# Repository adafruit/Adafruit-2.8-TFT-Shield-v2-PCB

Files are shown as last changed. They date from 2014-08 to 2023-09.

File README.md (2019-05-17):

# Adafruit 2.8 TFT LCD Display Shield v2 PCBs
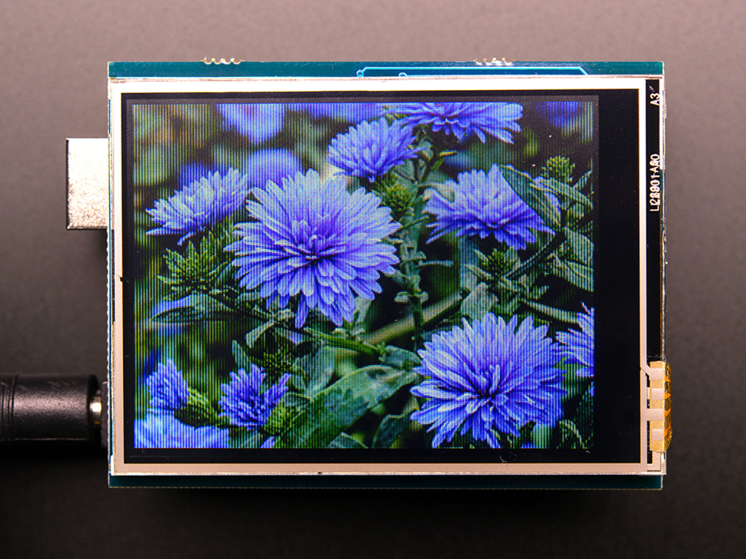
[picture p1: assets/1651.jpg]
&nbsp; 
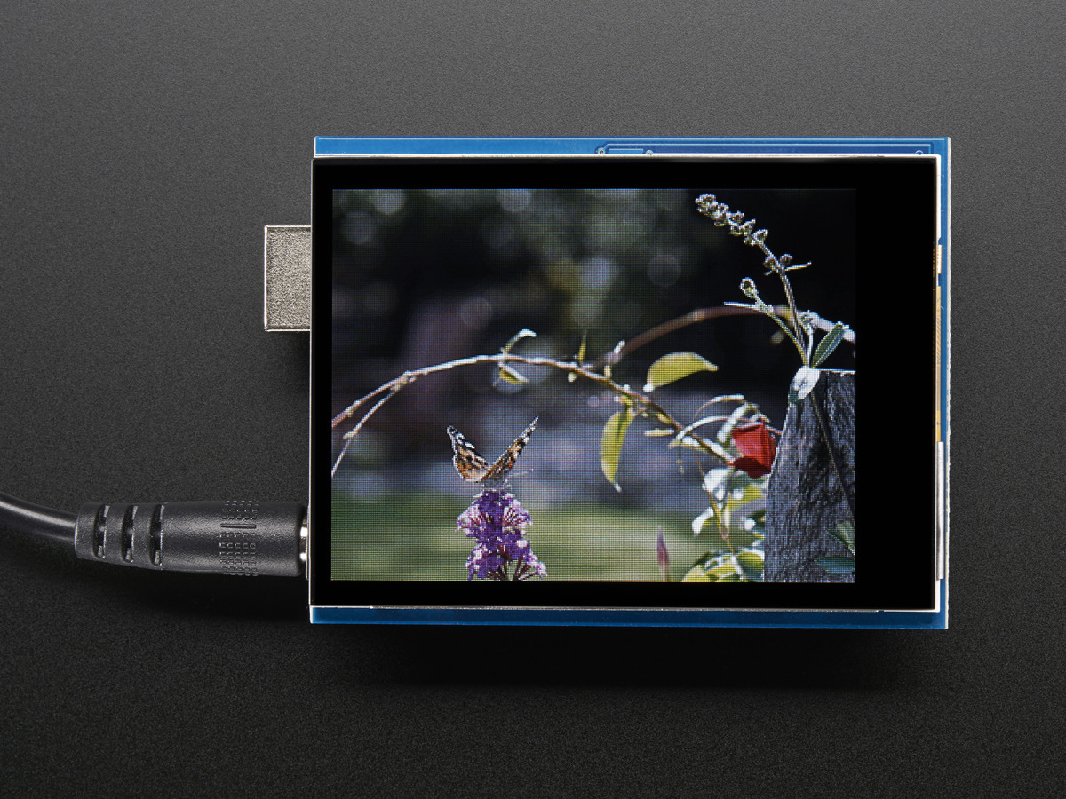
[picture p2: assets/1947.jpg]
<br />
Click to view/purchase from the Adafruit Shop:
- [2.8" TFT Touch Shield for Arduino with Resistive Touch Screen](https://www.adafruit.com/product/1651)
- [2.8" TFT Touch Shield for Arduino w/Capacitive Touch](https://www.adafruit.com/product/1947)

Spice up your Arduino project with a beautiful large touchscreen display shield with built in microSD card connection. This TFT display is big (2.8" diagonal) bright (4 white-LED backlight) and colorful (18-bit 262,000 different shades)! 240x320 pixels with individual pixel control. It has way more resolution than a black and white 128x64 display. As a bonus, these displays has a resistive or capacitive touchscreen attached to it already, so you can detect finger presses anywhere on the screen. 

We've updated our original v1 shield to an SPI display - its a tiny bit slower but uses a lot less pins and is now much easier to use with Mega & Leonardo. We also include an SPI touchscreen controller so you only need one additional pin to add a high quality touchscreen controller. Even with all the extras, the price is lower thanks to our parts sourcing & engineering skillz!

This is the PCB for the two Adafruit 2.8" TFT Shields v2 Resistive and Capacitive touch screens. 

The format is EagleCAD schematic and board layout

For more details, check out the product pages at

- https://www.adafruit.com/product/1651
- https://www.adafruit.com/product/1947

### License

Adafruit invests time and resources providing this open source design, please support Adafruit and open-source hardware by [purchasing products from Adafruit](https://www.adafruit.com)!

All text above must be included in any redistribution

Designed by Limor Fried/Ladyada for Adafruit Industries.
Creative Commons Attribution/Share-Alike, all text above must be included in any redistribution. 
See license.txt for additional information.

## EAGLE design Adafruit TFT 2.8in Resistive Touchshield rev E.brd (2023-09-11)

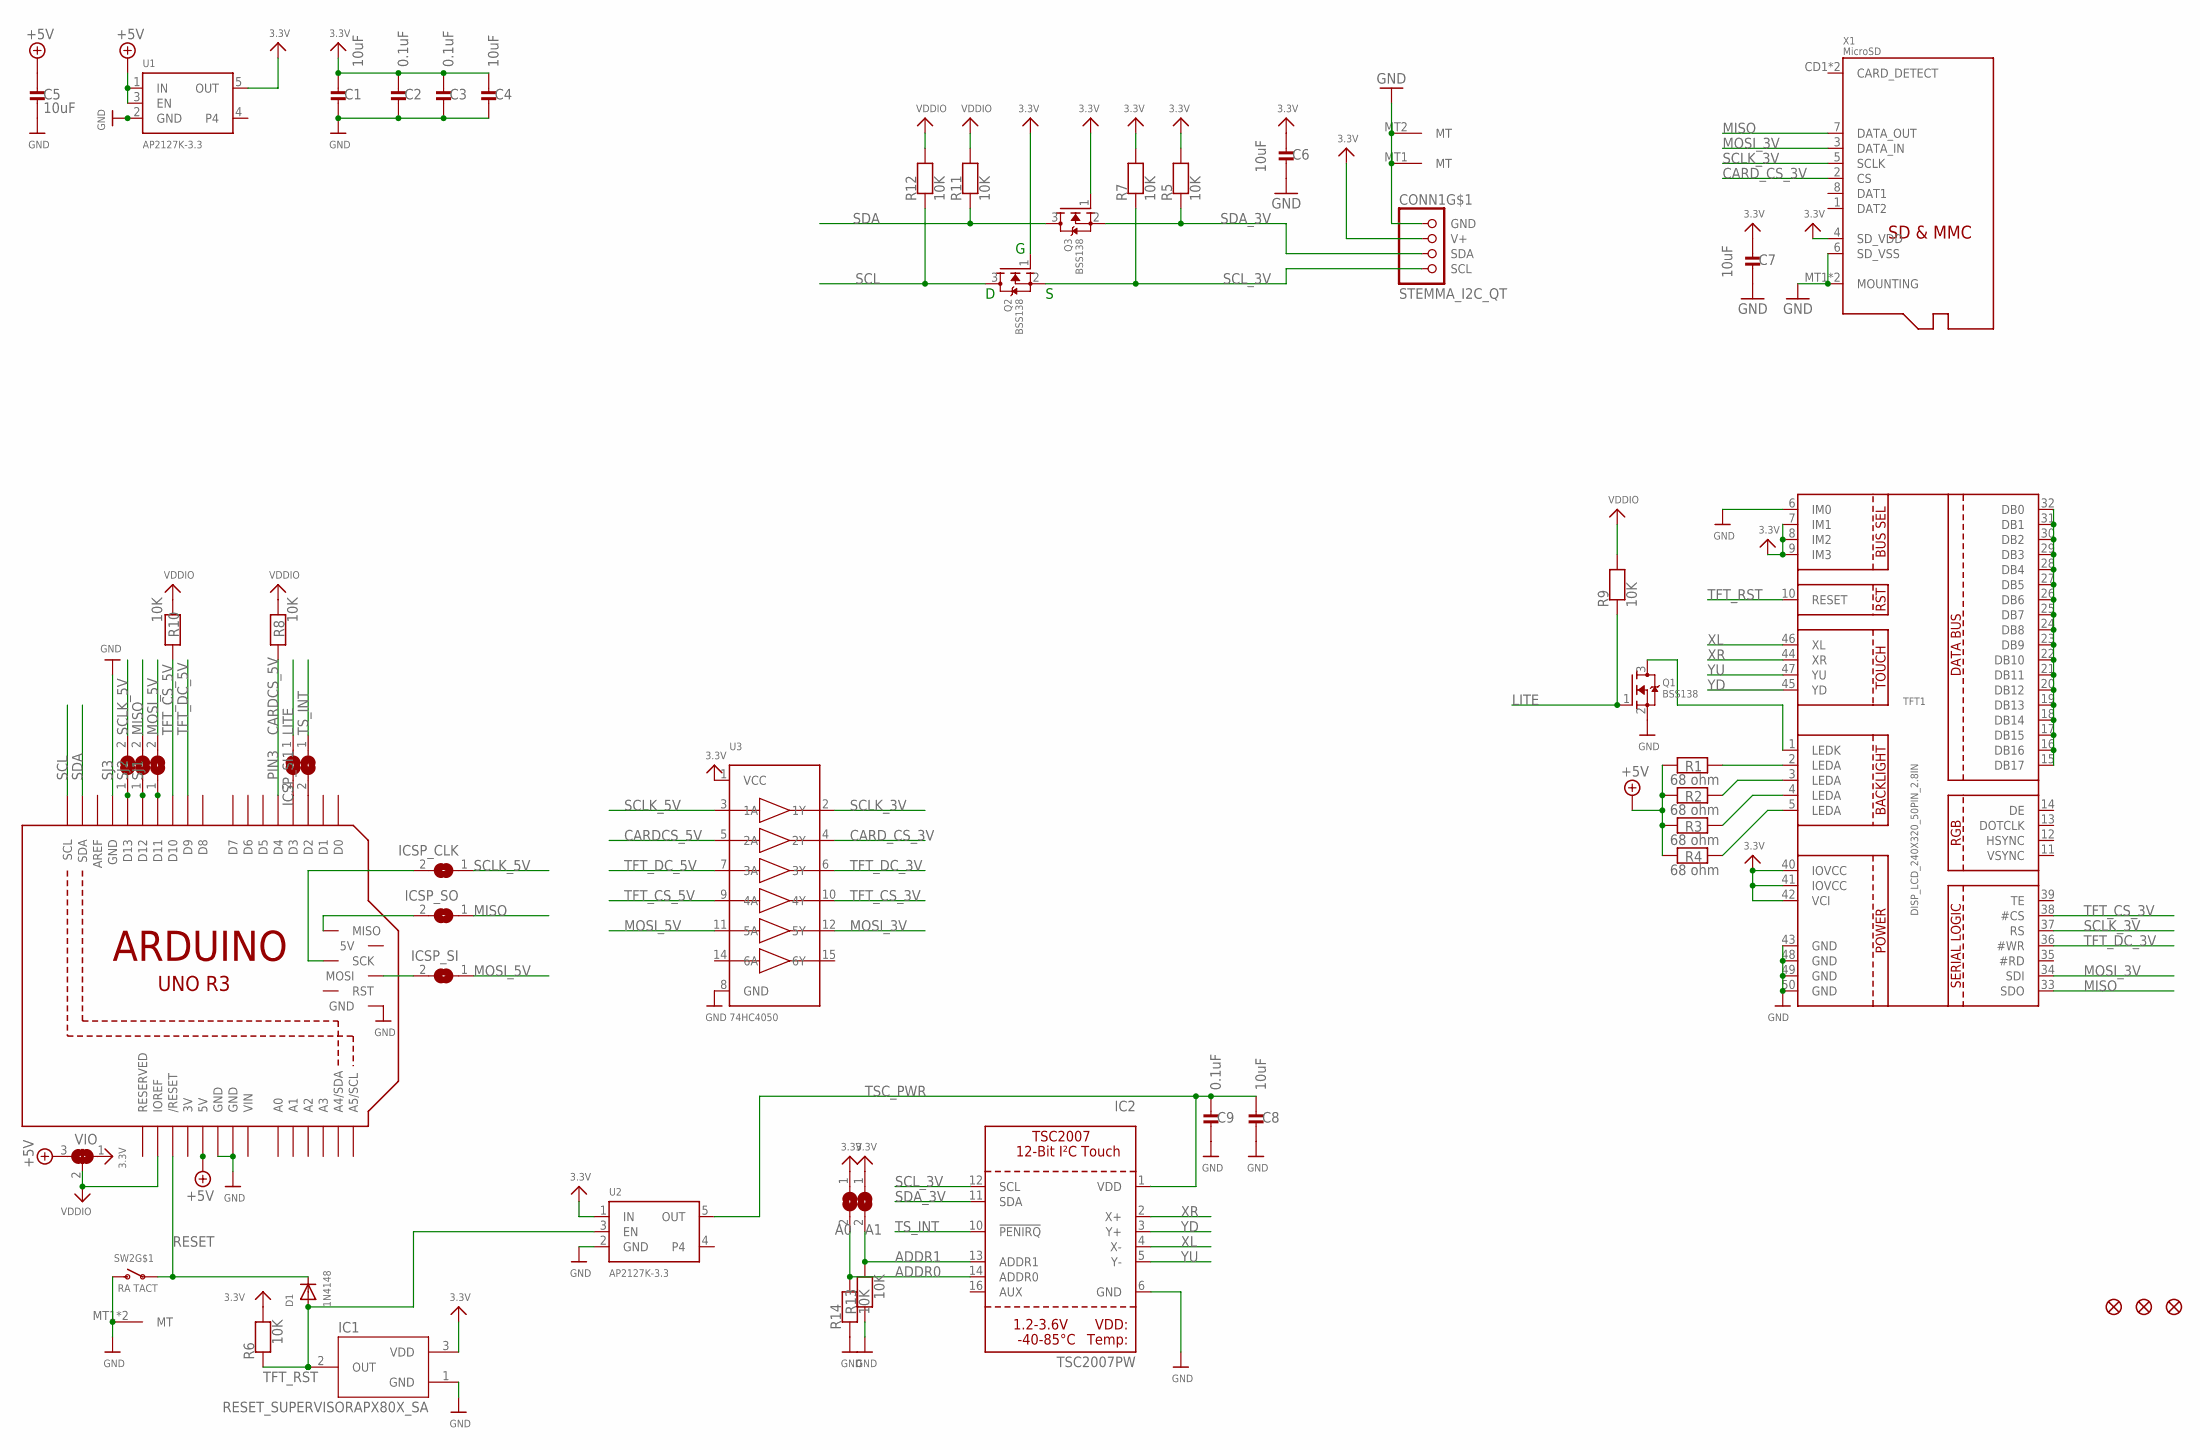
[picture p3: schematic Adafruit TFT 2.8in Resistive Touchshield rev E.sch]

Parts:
ARD: ARDUINO_R3_ICSPSMT; ARDUINOR3_ICSP_SMT
C1, C4, C5, C6, C7, C8: 10uF; 0805-NO
C2, C3, C9: 0.1uF; 0603-NO
CONN1: STEMMA_I2C_QT; JST_SH4
D1: 1N4148; SOD-323F
IC1: RESET_SUPERVISORAPX80X_SA; SOT23-WIDE
IC2: TSC2007PW; TSSOP16
ICSP_CLK: SOLDERJUMPERCLOSED; SOLDERJUMPER_CLOSEDWIRE
ICSP_CLK1: A1; SOLDERJUMPER_ARROW_NOPASTE
ICSP_CLK2: A0; SOLDERJUMPER_ARROW_NOPASTE
ICSP_SI, ICSP_SI1: SOLDERJUMPERCLOSED; SOLDERJUMPER_CLOSEDWIRE
ICSP_SO: SOLDERJUMPERCLOSED; SOLDERJUMPER_CLOSEDWIRE
PIN3: SOLDERJUMPER; SOLDERJUMPER_ARROW_NOPASTE
Q1, Q2, Q3: BSS138; SOT23-WIDE
R1, R2, R3, R4: 68 ohm; 0603-NO
R5, R6, R7, R8, R9, R10, R11, R12, R13, R14: 10K; 0603-NO
SJ1, SJ2, SJ3: SOLDERJUMPER; SOLDERJUMPER_ARROW_NOPASTE
SW2: RA TACT; SPST_TACTILE_RA
TFT1: DISP_LCD_240X320_50PIN_2.8IN; TFT_2.83IN_240X320_50PIN
U1, U2: AP2127K-3.3; SOT23-5
U3: 74HC4050; SOIC16
U$10, U$11, U$19: FIDUCIAL_1MM
VIO: SOLDERJUMPER_2WAY; SOLDERJUMPER_2WAY_OPEN_NOPASTE
X1: MicroSD; MICROSD

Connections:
3.3V: C1.1, C2.1, C3.1, C4.1, C6.1, C7.1, CONN1.2 (V+), IC1.3 (VDD), ICSP_CLK1.1, ICSP_CLK2.1, Q2.1 (G), Q3.1 (G), R5.2, R6.2, R7.2, TFT1.7 (IM1), TFT1.8 (IM2), TFT1.9 (IM3), TFT1.40 (IOVCC), TFT1.41 (IOVCC), TFT1.42 (VCI), U1.5 (OUT), U2.1 (IN), U3.1 (VCC), VIO.1, X1.4 (SD_VDD)
3V: ARD.3V
+5V: ARD.5V, C5.1, R1.1, R2.1, R3.1, R4.1, U1.1 (IN), U1.3 (EN), VIO.3
ADDR0: IC2.14 (ADDR0), ICSP_CLK2.2, R14.2
ADDR1: IC2.13 (ADDR1), ICSP_CLK1.2, R13.2
BACKLITE: ARD.D3, PIN3.2
CARDCS_5V: ARD.D4, R8.1, U3.5 (2A)
CARD_CS_3V: U3.4 (2Y), X1.2 (CS)
GND: ARD.GND, ARD.GND@1 (GND), ARD.GND@2 (GND), ARD.GND@3 (GND), C1.2, C2.2, C3.2, C4.2, C5.2, C6.2, C7.2, C8.2, C9.2, CONN1.1 (GND), CONN1.MT1 (MT), CONN1.MT2 (MT), IC1.1 (GND), IC2.6 (GND), Q1.2 (S), R13.1, R14.1, SW2.2 (S), SW2.MT1 (MT), SW2.MT2 (MT), TFT1.6 (IM0), TFT1.43 (GND), TFT1.48 (GND), TFT1.49 (GND), TFT1.50 (GND), U1.2 (GND), U2.2 (GND), U3.8 (GND), X1.6 (SD_VSS), X1.MT1 (MOUNTING), X1.MT2 (MOUNTING)
LITE: PIN3.1, Q1.1 (G), R9.1
MISO: ICSP_SO.1, SJ2.2, TFT1.33 (SDO), X1.7 (DATA_OUT)
MOSI_3V: TFT1.34 (SDI), U3.12 (5Y), X1.3 (DATA_IN)
MOSI_5V: ICSP_SI.1, SJ1.2, U3.11 (5A)
unnamed: Q1.3 (D), TFT1.1 (LEDK)
unnamed: R1.2, TFT1.2 (LEDA)
unnamed: R2.2, TFT1.3 (LEDA)
unnamed: R3.2, TFT1.4 (LEDA)
unnamed: ARD.MOSI, ICSP_SI.2
unnamed: ARD.D2, ICSP_SI1.2
unnamed: TFT1.15 (DB17), TFT1.16 (DB16), TFT1.17 (DB15), TFT1.18 (DB14), TFT1.19 (DB13), TFT1.20 (DB12), TFT1.21 (DB11), TFT1.22 (DB10), TFT1.23 (DB9), TFT1.24 (DB8), TFT1.25 (DB7), TFT1.26 (DB6), TFT1.27 (DB5), TFT1.28 (DB4), TFT1.29 (DB3), TFT1.30 (DB2), TFT1.31 (DB1), TFT1.32 (DB0)
unnamed: R4.2, TFT1.5 (LEDA)
unnamed: ARD.MISO, ICSP_SO.2
unnamed: ARD.SCK, ICSP_CLK.2
unnamed: ARD.D13, SJ3.1
unnamed: ARD.D12, SJ2.1
unnamed: ARD.D11, SJ1.1
RESET: ARD.RESET (/RESET), D1.C, SW2.1
SCL: ARD.SCL, Q2.3 (D), R12.1
SCLK_3V: TFT1.37 (RS), U3.2 (1Y), X1.5 (SCLK)
SCLK_5V: ICSP_CLK.1, SJ3.2, U3.3 (1A)
SCL_3V: CONN1.4 (SCL), IC2.12 (SCL), Q2.2 (S), R7.1
SDA: ARD.SDA, Q3.3 (D), R11.1
SDA_3V: CONN1.3 (SDA), IC2.11 (SDA), Q3.2 (S), R5.1
TFT_CS_3V: TFT1.38 (#CS), U3.10 (4Y)
TFT_CS_5V: ARD.D10, R10.1, U3.9 (4A)
TFT_DC_3V: TFT1.36 (#WR), U3.6 (3Y)
TFT_DC_5V: ARD.D9, U3.7 (3A)
TFT_RST: D1.A, IC1.2 (OUT), R6.1, TFT1.10 (RESET), U2.3 (EN)
TSC_PWR: C8.1, C9.1, IC2.1 (VDD), U2.5 (OUT)
TS_INT: IC2.10 (!PENIRQ), ICSP_SI1.1
VDDIO: ARD.IOREF, R8.2, R9.2, R10.2, R11.2, R12.2, VIO.2
VIN: ARD.VIN
XL: IC2.4 (X-), TFT1.46 (XL)
XR: IC2.2 (X+), TFT1.44 (XR)
YD: IC2.3 (Y+), TFT1.45 (YD)
YU: IC2.5 (Y-), TFT1.47 (YU)

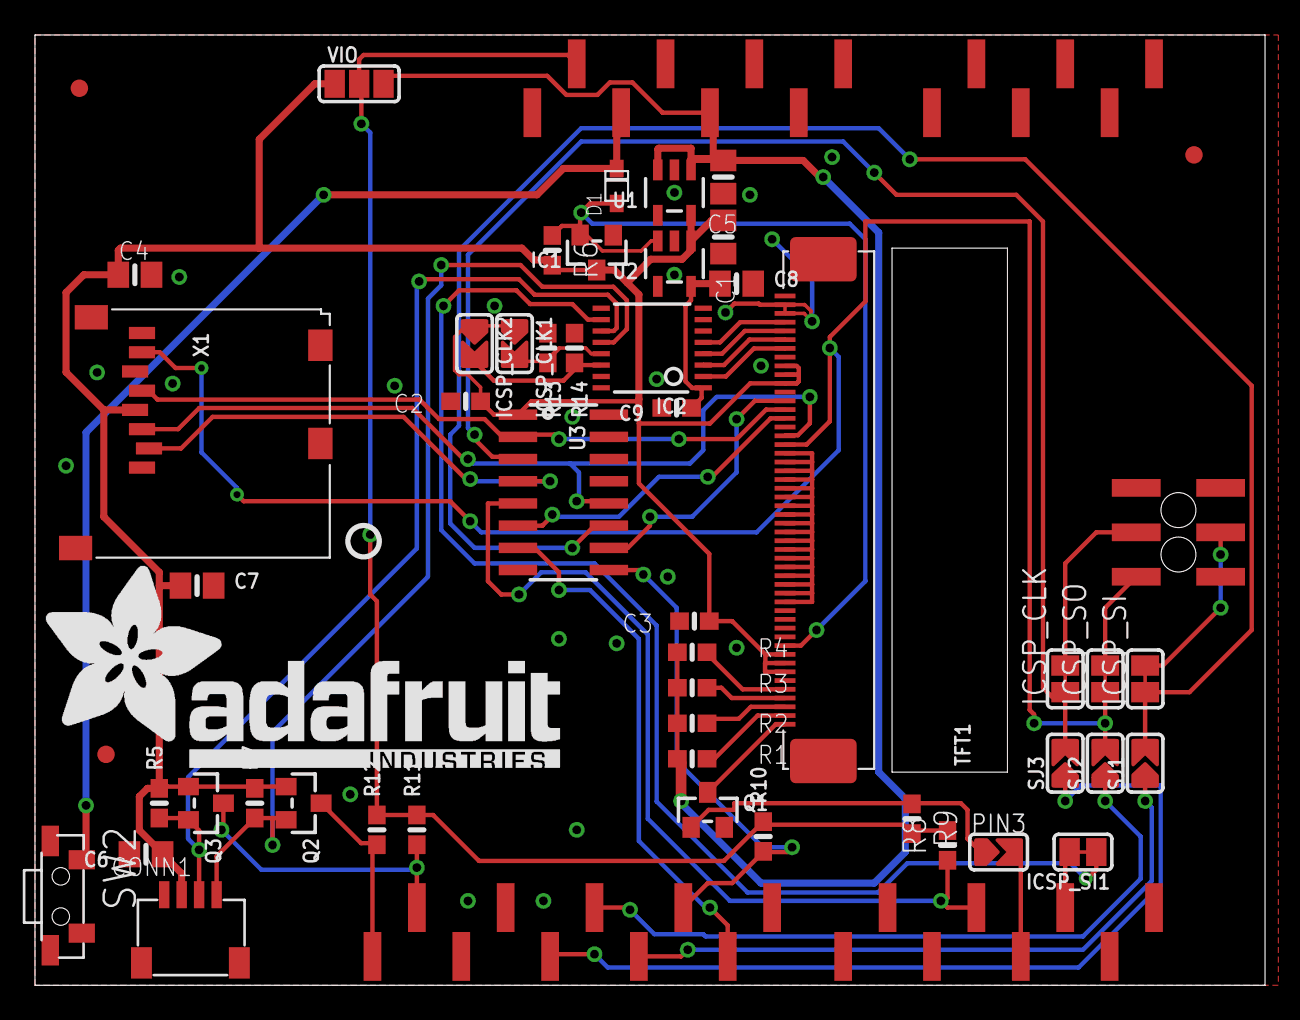
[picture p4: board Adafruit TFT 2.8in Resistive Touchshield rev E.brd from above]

Board: 2 copper layers, 70.4 x 54.4 mm, 76 parts (2 on the bottom side), 44 nets.

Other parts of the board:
PLABEL0: PLABEL0
PLABEL1: PLABEL1
PLABEL2: PLABEL2
PLABEL3: PLABEL3
PLABEL4: PLABEL4
PLABEL5: PLABEL5
PLABEL6: PLABEL6
PLABEL7: PLABEL7
PLABEL8: PLABEL8
PLABEL9: PLABEL9
PLABEL10: PLABEL10
PLABEL11: PLABEL11
PLABEL12: PLABEL12
PLABEL13: PLABEL13
PLABEL14: PLABEL14
PLABEL15: PLABEL15
PLABEL16: PLABEL16
PLABEL17: PLABEL17
PLABEL18: PLABEL18
PLABEL19: PLABEL19
PLABEL20: PLABEL20
PLABEL21: PLABEL21
PLABEL22: PLABEL22
U$3: PCBFEAT-REV-040
U$20: ADAFRUIT_TEXT_30MM

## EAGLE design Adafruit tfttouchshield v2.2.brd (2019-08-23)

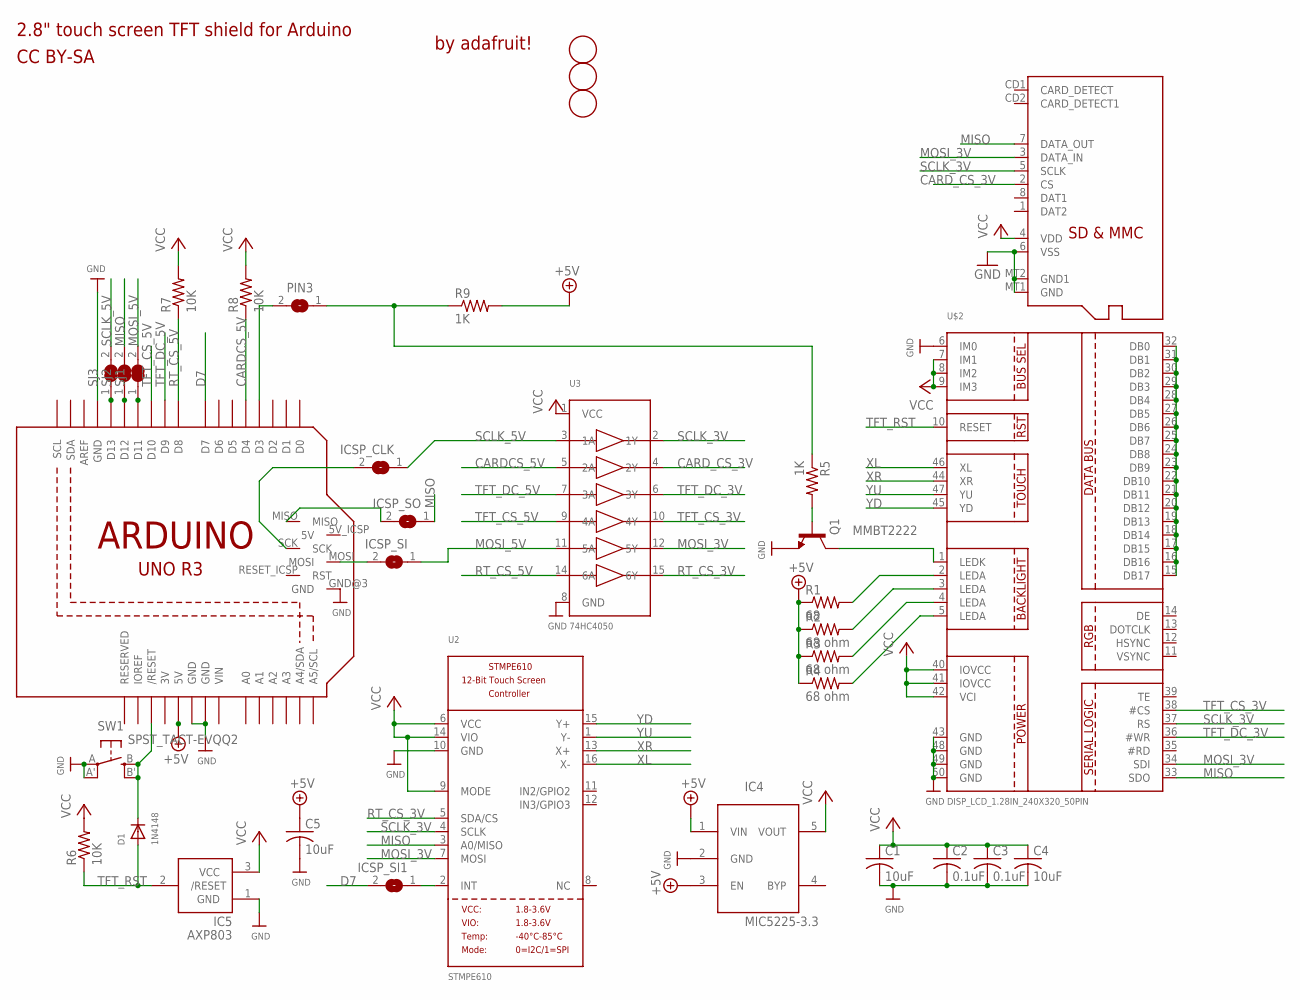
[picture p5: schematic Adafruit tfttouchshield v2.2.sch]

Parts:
C1, C4, C5: 10uF; C0805K
C2, C3: 0.1uF; C0805K
D1: 1N4148; SOD-323F
IC4: MIC5225-3.3; SOT23-5L
IC5: AXP803; SOT23
ICSP_CLK: SOLDERJUMPERREFLOW_NOPASTE; SOLDERJUMPER_REFLOW_NOPASTE
ICSP_SI, ICSP_SI1: SOLDERJUMPERREFLOW_NOPASTE; SOLDERJUMPER_REFLOW_NOPASTE
ICSP_SO: SOLDERJUMPERREFLOW_NOPASTE; SOLDERJUMPER_REFLOW_NOPASTE
PIN3: SOLDERJUMPERREFLOW_NOPASTE; SOLDERJUMPER_REFLOW_NOPASTE
Q1: MMBT2222; SOT23-BEC
R1: 68; R0805
R2, R3, R4: 68 ohm; R0805
R5, R9: 1K; R0805
R6, R7, R8: 10K; R0805
SJ1, SJ2, SJ3: SOLDERJUMPER_CLOSED; SOLDERJUMPER_CLOSEDWIRE
SW1: SPST_TACT-EVQQ2; EVQ-Q2
U2: STMPE610; QFN16_3MM
U3: 74HC4050; SOIC16
U$2: DISP_LCD_1.28IN_240X320_50PIN; TFT_2.83IN_240X320_50PIN
U$3: MICROSD
U$10, U$11, U$19: FIDUCIAL; FIDUCIAL_1MM
U$17: ARDUINO_R3_ICSPSMT; ARDUINOR3_ICSP_SMT

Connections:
3V: U$17.3V
+5V: C5.1, IC4.1 (VIN), IC4.3 (EN), R1.1, R2.1, R3.1, R4.1, R9.2, U$17.5V
CARDCS_5V: R8.1, U3.5 (2A), U$17.D4
CARD_CS_3V: U3.4 (2Y), U$3.2 (CS)
D7: ICSP_SI1.2, U$17.D7
GND: C1.2, C2.2, C3.2, C4.2, C5.2, IC4.2 (GND), IC5.1 (GND), Q1.E, SW1.A, SW1.A' (P1), U2.10 (GND), U3.8 (GND), U$2.6 (IM0), U$2.43 (GND), U$2.48 (GND), U$2.49 (GND), U$2.50 (GND), U$3.6 (VSS), U$3.MT1 (GND), U$3.MT2 (GND1), U$17.GND, U$17.GND@1 (GND), U$17.GND@2 (GND), U$17.GND@3 (GND)
MISO: ICSP_SO.1, SJ2.2, U2.3 (A0/MISO), U$2.33 (SDO), U$3.7 (DATA_OUT)
MOSI_3V: U2.7 (MOSI), U3.12 (5Y), U$2.34 (SDI), U$3.3 (DATA_IN)
MOSI_5V: ICSP_SI.1, SJ1.2, U3.11 (5A)
unnamed: Q1.C, U$2.1 (LEDK)
unnamed: R1.2, U$2.2 (LEDA)
unnamed: R2.2, U$2.3 (LEDA)
unnamed: R3.2, U$2.4 (LEDA)
unnamed: PIN3.1, R5.1, R9.1
unnamed: ICSP_SI.2, U$17.MOSI
unnamed: PIN3.2, U$17.D3
unnamed: D1.C, SW1.B (S), SW1.B' (S1), U$17.RESET (/RESET)
unnamed: U$2.15 (DB17), U$2.16 (DB16), U$2.17 (DB15), U$2.18 (DB14), U$2.19 (DB13), U$2.20 (DB12), U$2.21 (DB11), U$2.22 (DB10), U$2.23 (DB9), U$2.24 (DB8), U$2.25 (DB7), U$2.26 (DB6), U$2.27 (DB5), U$2.28 (DB4), U$2.29 (DB3), U$2.30 (DB2), U$2.31 (DB1), U$2.32 (DB0)
unnamed: R4.2, U$2.5 (LEDA)
unnamed: ICSP_SO.2, U$17.MISO
unnamed: ICSP_CLK.2, U$17.SCK
unnamed: SJ3.1, U$17.D13
unnamed: SJ2.1, U$17.D12
unnamed: SJ1.1, U$17.D11
unnamed: Q1.B, R5.2
RT_CS_3V: U2.5 (SDA/CS), U3.15 (6Y)
RT_CS_5V: R7.1, U3.14 (6A), U$17.D8
SCLK_3V: U2.4 (SCLK), U3.2 (1Y), U$2.37 (RS), U$3.5 (SCLK)
SCLK_5V: ICSP_CLK.1, SJ3.2, U3.3 (1A)
TFT_CS_3V: U3.10 (4Y), U$2.38 (#CS)
TFT_CS_5V: U3.9 (4A), U$17.D10
TFT_DC_3V: U3.6 (3Y), U$2.36 (#WR)
TFT_DC_5V: U3.7 (3A), U$17.D9
TFT_RST: D1.A, IC5.2 (/RESET), R6.1, U$2.10 (RESET)
TS_INT: ICSP_SI1.1, U2.2 (INT)
VCC: C1.1, C2.1, C3.1, C4.1, IC4.5 (VOUT), IC5.3 (VCC), R6.2, R7.2, R8.2, U2.6 (VCC), U2.9 (MODE), U2.14 (VIO), U3.1 (VCC), U$2.7 (IM1), U$2.8 (IM2), U$2.9 (IM3), U$2.40 (IOVCC), U$2.41 (IOVCC), U$2.42 (VCI), U$3.4 (VDD)
VIN: U$17.VIN
XL: U2.16 (X-), U$2.46 (XL)
XR: U2.13 (X+), U$2.44 (XR)
YD: U2.15 (Y+), U$2.45 (YD)
YU: U2.1 (Y-), U$2.47 (YU)

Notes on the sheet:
2.8" touch screen TFT shield for Arduino
by adafruit!
CC BY-SA

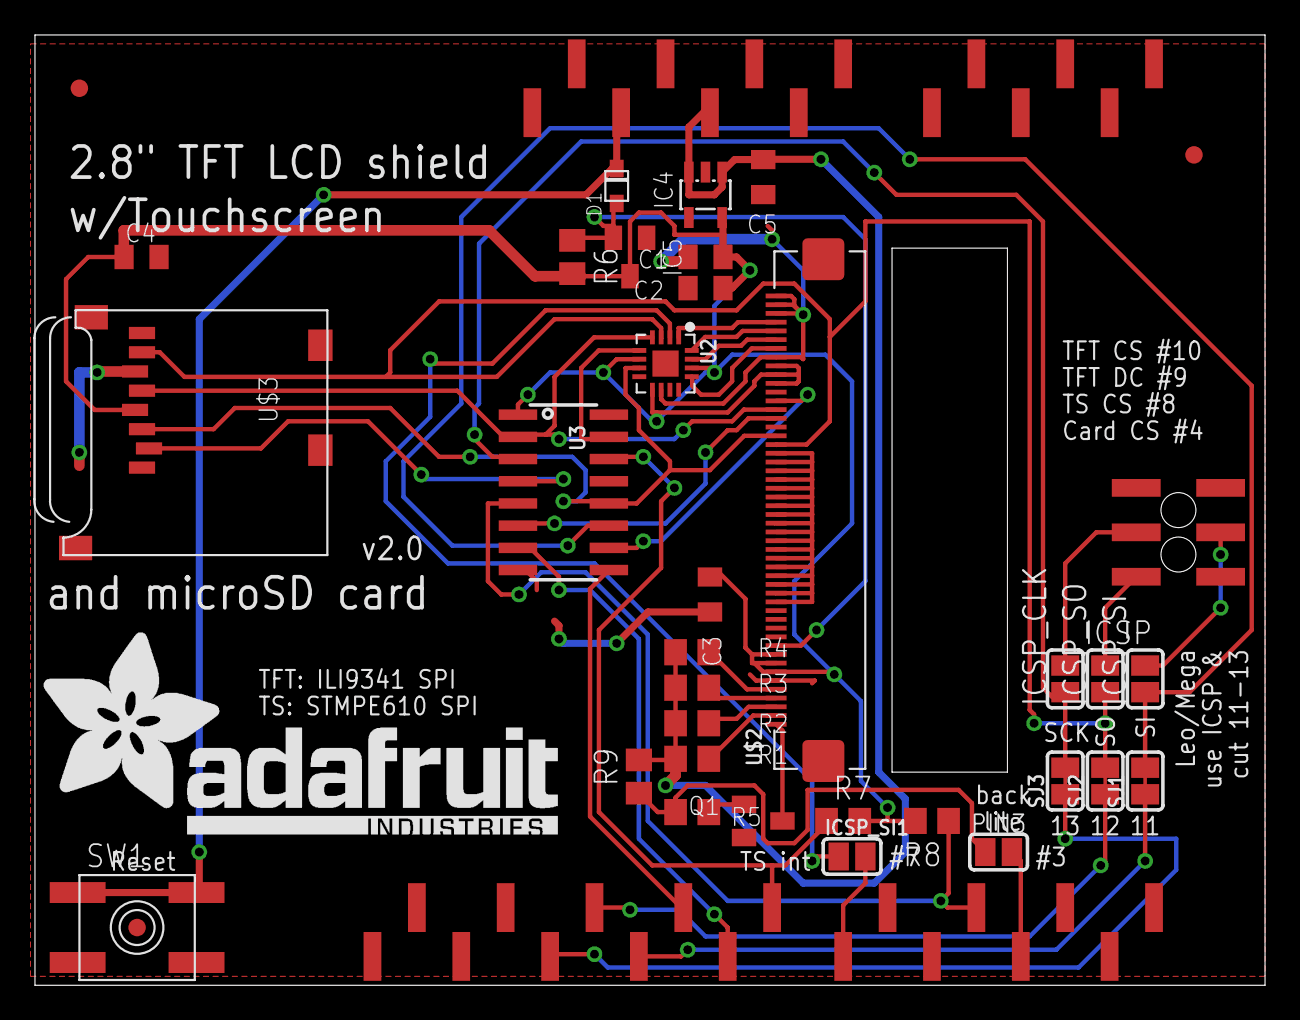
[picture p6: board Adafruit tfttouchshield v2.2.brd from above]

Board: 2 copper layers, 70.4 x 54.4 mm, 36 parts (2 on the bottom side), 39 nets.

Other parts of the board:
U$20: ADAFRUIT_TEXT_30MM

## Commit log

2019-08-23 Updated to latest versions
    [Adafruit tftcaptouchshield rev C.brd, Adafruit tftcaptouchshield rev C.sch, Adafruit tftcaptouchshield v2.3.sch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]
2023-09-11 adding rev E files
    [Adafruit TFT 2.8in Resistive Touchshield rev E.brd, Adafruit TFT 2.8in Resistive Touchshield rev E.sch]
